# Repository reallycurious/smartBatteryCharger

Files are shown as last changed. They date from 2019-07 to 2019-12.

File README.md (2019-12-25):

# smartBatteryCharger (incomplete)
PIC12F1572 based Charger for 14.4V cordless drill

<b>Warning:</b> This charger design and accompanying code is based on a lot of assumptions. Some of which may or might not hold true. So if you want to adopt this design and/or code do so at your own risk.

After building a 2 meter by 2 meter cupboard and fastening all screws by hand I decided that a cordless drill is needed. So I bought the most inexpensive one I found. This cordless drill came with a 18v 400ma rated power adapter and charger stand that consists of few simple passive components: A 2W 10 Ohm resistor, an 4007 diode, two 3mm leds and two smd 0805 resistors one 2 KOhm the other 100 Ohm. Oh and instructions to charge 3-5 hours: which resulted in a very hot battery. I feared that it might vent electrolyte so I decided to replace electronics in charger stand, making it smarter.
  
So where to start designing a smart charger circuit that fits in housing of the old dumb one: a net search gave some ideas. Article <a href="https://batteryuniversity.com/learn/article/charging_nickel_based_batteries">Charging Nickel-cadmium @ batteryuniversity.com</a> is helpful but insufficient for designing a charger. <a href="http://electronics-diy.com/electronic_schematic.php?id=813">Intelligent NiCd/NiMH Battery Charger @ electronics-diy.com</a> was better: Although there is no source code as the author states "The source code is not freeware or shareware so please don't ask me to mail you the source code as it has commercial applications" reading the article gives a clear idea on how a smart chager should work and helped me designing the algorithm. <a href="https://electrosome.com/uart-pic-microcontroller-mplab-xc8/">Using UART of PIC Microcontroller – MPLAB XC8 @ electrosome.com</a> was helpful designing uart code. I had no such luck in pwm code, no practical examples for pic12f1572, so I cooked something from datasheet. Thankfully datasheet had sample assembly code for ADC.
  
You might ask, why pic12f1572 ? because with a 3,5 TL price tag for <a href="https://www.direnc.net/pic12f1572t-i-mf-dfn8-8bit-32mhz-mikrodenetleyici">dfn footprint version</a>, it was the cheapest but capable microcontroller that I could find at the time. And except its 10 bit ADC (not 12 bit) I think it is very suitable for the task. I should add that I had not programmed a PIC micro before. I had to learn pic programming (mostly reading the datasheet) for programming the pic12f1572.

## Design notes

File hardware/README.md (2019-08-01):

<b>WARNING: EXPERIMENTAL DESIGN</b><p>
<b>WARNING: DONT USE LINEAR VOLTAGE REGULATOR</b><p>

Linear Voltage Regulator Heat Up, may fry microcontroller (already had fried one microcontroller with LM7805) 
Currently using <a href="http://www.romanblack.com/smps/smps.htm">http://www.romanblack.com/smps/smps.htm</a> as smps. 
I might also use a buck converter ic.

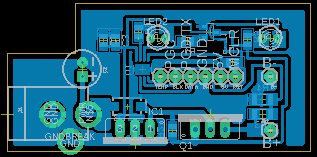
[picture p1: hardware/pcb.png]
pcb</img>
<p>
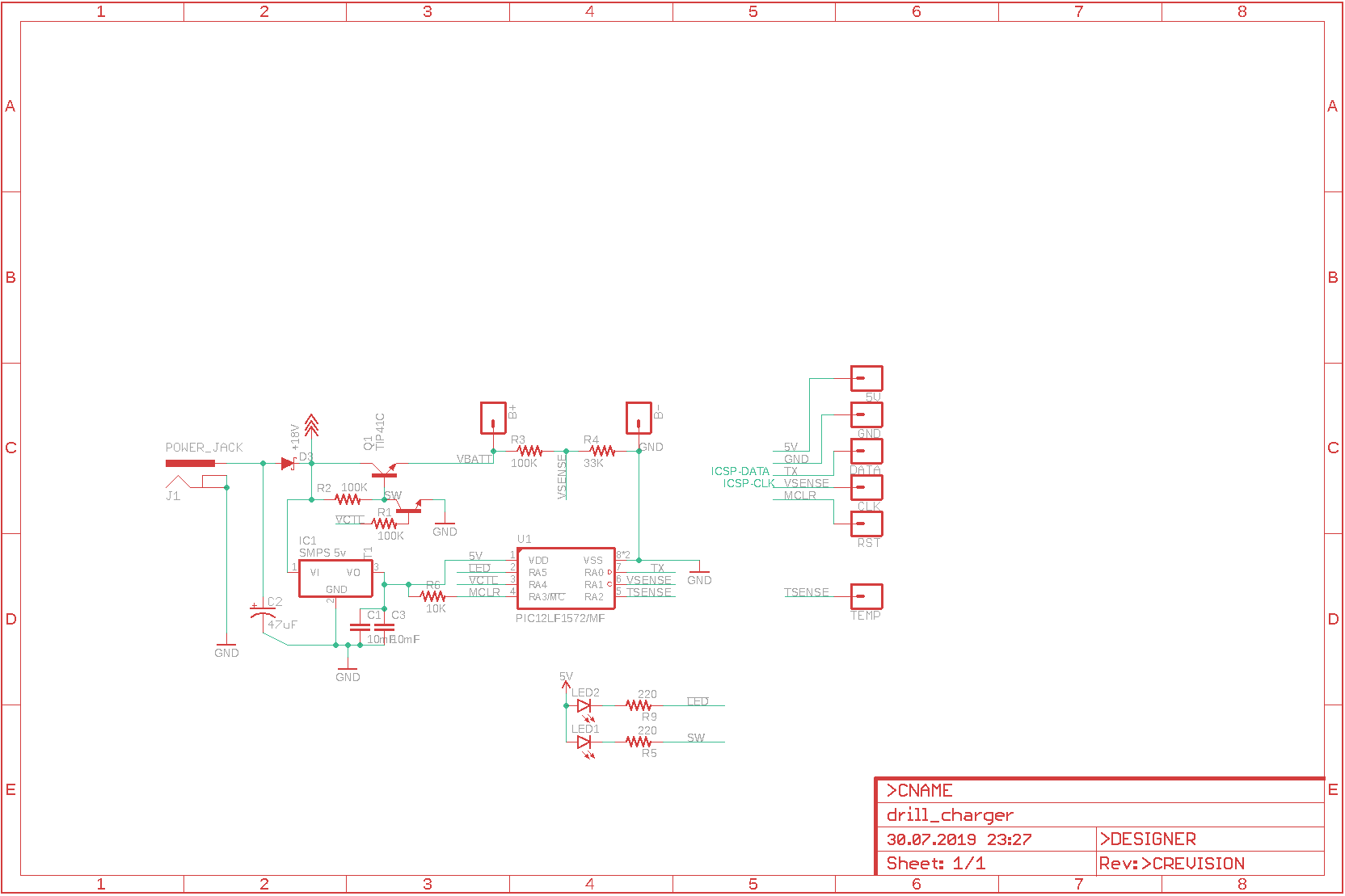
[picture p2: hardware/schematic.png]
schematic</img>

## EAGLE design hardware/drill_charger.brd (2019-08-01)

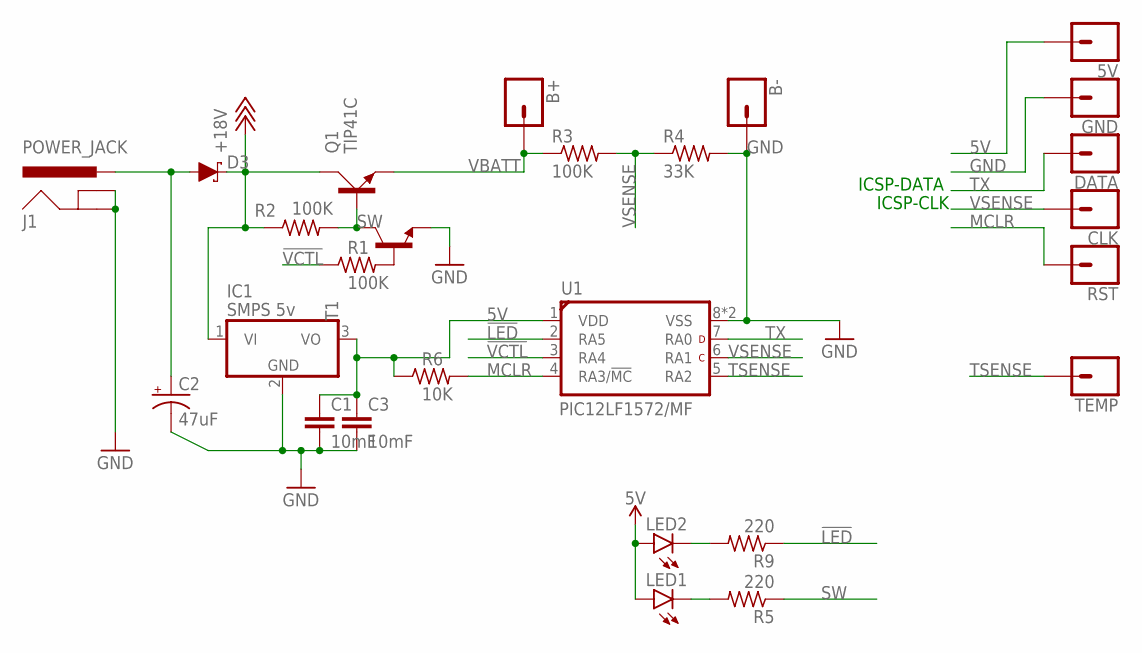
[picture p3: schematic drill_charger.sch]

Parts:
5V: CONN_01; 1X01
B+: CONN_01; 1X01
B-: CONN_01; 1X01
C1, C3: 10mF; C0805
C2: 47uF; CPOL-RADIAL-2.5MM-6.5MM
CLK: CONN_01; 1X01
D3: 1A/40V/500mV; SMA-DIODE
DATA: CONN_01; 1X01
GND: CONN_01; 1X01
IC1: SMPS 5v; TO220V
J1: POWER_JACK; POWER_JACK_PTH
LED1, LED2: LED3MM
Q1: TIP41C; TO220AV
R1, R2: 100K; R0805
R3: 100K; R1206
R4: 33K; R1206
R5, R9: 220; R0805
R6: 10K; R0805
RST: CONN_01; 1X01
T1: MMBT3904LT1-NPN-SOT23-BEC; SOT23-BEC
TEMP: CONN_01; 1X01
U1: PIC12LF1572/MF; DFN8-MF

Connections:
5V: 5V.1, C1.1, C3.1, IC1.3 (VO), LED1.A, LED2.A, R6.1, U1.1 (VDD)
!LED: R9.1, U1.2 (RA5)
!VCTL: R1.1, U1.3 (RA4)
+18V: D3.C, IC1.1 (VI), Q1.C, R2.1
GND: B-.1, C1.2, C2.2 (-), C3.2, GND.1, IC1.2 (GND), J1.GND, J1.GNDBREAK, R4.2, T1.E, U1.8 (VSS), U1.EP (VSS)
MCLR: R6.2, RST.1, U1.4 (RA3/!MC!)
unnamed: LED2.K (C), R9.2
unnamed: LED1.K (C), R5.2
unnamed: C2.1 (+), D3.A, J1.PWR
unnamed: R1.2, T1.B
SW: Q1.B, R2.2, R5.1, T1.C
TSENSE: TEMP.1, U1.5 (RA2)
TX: DATA.1, U1.7 (RA0)
VBATT: B+.1, Q1.E, R3.1
VSENSE: CLK.1, R3.2, R4.1, U1.6 (RA1)

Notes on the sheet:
ICSP-DATA
ICSP-CLK

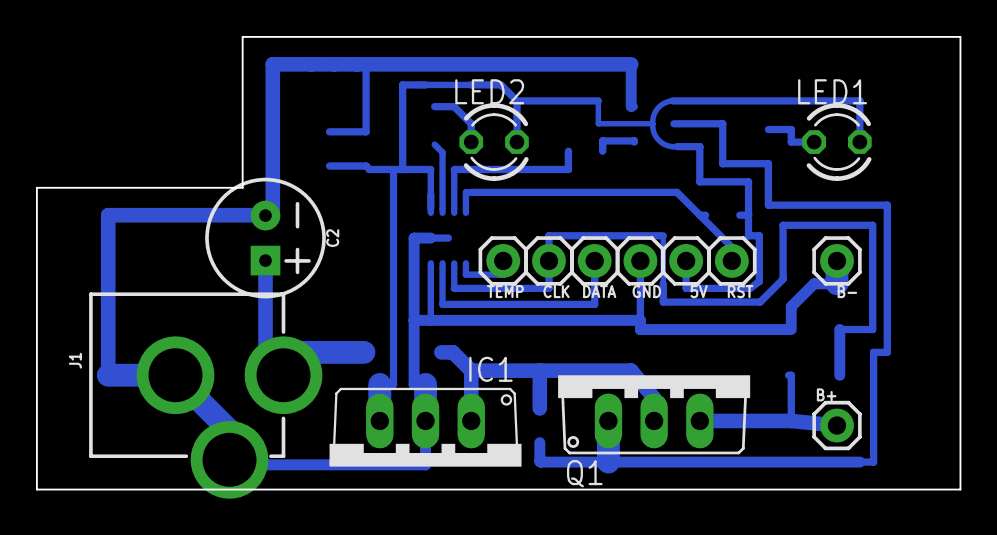
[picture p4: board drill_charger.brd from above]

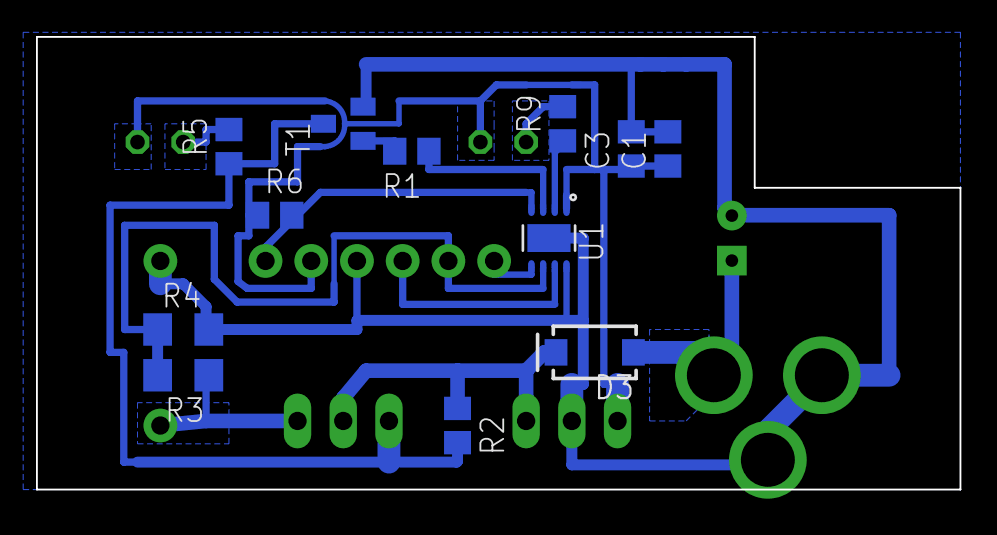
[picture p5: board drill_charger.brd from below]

Board: 2 copper layers, 51.3 x 25.1 mm, 26 parts (12 on the bottom side), 15 nets.

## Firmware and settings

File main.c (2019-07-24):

/*
 * File:   main.c
 * Author: storm
 *
 * Created on March 9, 2019, 5:36 PM
 */

// PIC12F1572 Configuration Bit Settings

// 'C' source line config statements

// CONFIG1
#pragma config FOSC = INTOSC    //  (INTOSC oscillator; I/O function on CLKIN pin)
#pragma config WDTE = ON        // Watchdog Timer Enable (WDT enabled)
#pragma config PWRTE = OFF      // Power-up Timer Enable (PWRT disabled)
#pragma config MCLRE = ON       // MCLR Pin Function Select (MCLR/VPP pin function is MCLR)
#pragma config CP = OFF         // Flash Program Memory Code Protection (Program memory code protection is disabled)
#pragma config BOREN = ON       // Brown-out Reset Enable (Brown-out Reset enabled)
#pragma config CLKOUTEN = OFF   // Clock Out Enable (CLKOUT function is disabled. I/O or oscillator function on the CLKOUT pin)

// CONFIG2
#pragma config WRT = OFF        // Flash Memory Self-Write Protection (Write protection off)
#pragma config PLLEN = OFF      // PLL Enable (4x PLL disabled)
#pragma config STVREN = ON      // Stack Overflow/Underflow Reset Enable (Stack Overflow or Underflow will cause a Reset)
#pragma config BORV = LO        // Brown-out Reset Voltage Selection (Brown-out Reset Voltage (Vbor), low trip point selected.)
#pragma config LPBOREN = OFF    // Low Power Brown-out Reset enable bit (LPBOR is disabled)
#pragma config LVP = ON         // Low-Voltage Programming Enable (Low-voltage programming enabled)

// #pragma config statements should precede project file includes.
// Use project enums instead of #define for ON and OFF.

//_XTAL_FREQ defined in main.h

#include "main.h"
#include <xc.h>
#include <pic12f1572.h>
#include <stdint.h>
#include <stdio.h>

//Charger states
#define STAND_BY    0
#define COOL_DOWN   1
#define SOFT_CHARGE 2
#define FAST_CHARGE 3
#define TRICKLE     4
#define CHRG_ERROR  255

//Other
#define vChannel    1   //channel for voltage read
#define chargePin   4   //PORTA 4 and PWM2 is reassigned to A4 in code
#define pwmChannel  2
#define ledPin      5   //PORTA 5

//pic12F1572 adc 10 bit (ref voltage 5V = 1024 => 1 unit 4,8828125 mV) 
//voltage divider R1=100K R2=33K (V0=(R1+R2/R2)*V1) v0=4,0303030303*v1
//1 unit is 4,0303030303 * 4,8828125 mV = 19,6792140151 mV ~ 20mV 
#define vUNIT 20 //20mV = 0.02v
#define vDISCONNECT 2*1000/vUNIT //2000mv (2 volt)
#define vERROR  10*1000/vUNIT //10000mv (10 volt)
#define vDELTA 60/vUNIT //12*5mV = 60mV (Charge cut off negative delta voltage / 5mV per cell)
#define MAX_VOLTAGE 19*1000/vUNIT //19v
#define MAX_PLATEAU 15*60   //15 minutes
#define MAX_CTIME  3*60*60 //3 hours

//function defines
#define readVoltage() aRead(vChannel)
#define chargeOn() chargePWM(255)
#define chargeOff() chargePWM(0)
#define ledOn() PORTA &= ~(1 << ledPin)
#define ledOff() PORTA |= (1 << ledPin)
#define ledToggle() PORTA ^= (1 << ledPin) //^ XOR

//TEXT
const char hello[]= "Smart Charger v1.0\r\n";

//VARS
char cState = STAND_BY; //Charger state 0 (stand by)
unsigned short vPeak = 0;
unsigned short plateauCounter = 0;
unsigned long chargeCounter = 0;


void chargePWM(unsigned char duty)
{           
    duty = ~duty; //reverse duty    
    if (duty == 0)
        PORTA &= ~(1 << chargePin);  
    else if (duty == 255)
        PORTA |= (1 << chargePin); 
    else
        initPWM(pwmChannel, duty); 
}

char batteryConnected()
{
    chargeOff();    
    if (readVoltage() < vDISCONNECT) return 0;
    return 1;
}

void Serial_Write_Text(char *text)
{
  short i = 0;
  while (text[i] != '\0')
  {
      UART_Write(text[i]);
      i ++;
  }   
}

void Serial_Write_Int(int i)
{
    char text_buffer[10];
    
    sprintf(text_buffer, "%d", i);        
    Serial_Write_Text((char *)text_buffer);
}

void Serial_Write_Volt(int v)
{
    int dec = v/51;
    int frac =(v%51)*2*100;
    frac = frac /51;
             
    Serial_Write_Int(dec);
    Serial_Write_Text((char *)".");
    Serial_Write_Int(frac);
}

void Serial_Write_Time(int time)
{
    char hour = time/3600;    
    char minute = (time%3600)/60;
    char second = time%60;  
             
    Serial_Write_Int(hour);
    Serial_Write_Text((char *)":");
    Serial_Write_Int(minute);
    Serial_Write_Text((char *)":");
    Serial_Write_Int(second);    
}

void checkDelta(int voltage)
{   
    //limit control
    if ( (plateauCounter > MAX_PLATEAU) || (voltage > MAX_VOLTAGE) )
        cState = TRICKLE;               
    //routine
    if (voltage > vPeak) 
            {
                plateauCounter = 0; //zero plateau counter
                vPeak = voltage;
            }                
    else if ( (vPeak - voltage) > vDELTA) 
        cState = TRICKLE;
    else //vCycle <= vPeak -> start timer                 
        plateauCounter++;    
}

void delay_1ms()
{
    __delay_ms(1); // Wait 1 ms
}

void delay_125ms()
{
    __delay_ms(125); // Wait 125 ms
}

void delay_1s()
{
    __delay_ms(1000); // Wait 1 s
}

void setup()
{
//BOOT UP HERE
    CLRWDT();   //clear watchdog timer
    delay_1ms(); // 1 ms Delay
    initADC(vChannel);
    //Start serial
    UART_Init_tx_only(9600);
    Serial_Write_Text((char *)hello);
    //Check if a battery is connected
    chargeOff();
    if (! batteryConnected())    
    {
        //Self Test
        chargeOn();
        delay_1s(); // 1 Second Delay
        if (readVoltage() < vERROR) cState = CHRG_ERROR;
        chargeOff();
    }
//END BOOT    
}

void loop()
{
    short vCycle = 0; //zero vCycle for averaging
    CLRWDT();   //clear watchdog timer
    switch(cState)
    {
        case STAND_BY:
            chargeOff();  
            ledOn();
            delay_1s();
            if (batteryConnected() ) 
                cState = COOL_DOWN;
            break;
        case COOL_DOWN: 
            ledOff();            
            for (char iCycle = 0; iCycle < 8; iCycle++) 
            {
                delay_125ms(); // Wait 125 ms
                vCycle += readVoltage();                           
            }                            
            vCycle = vCycle >> 3; //divide by 8                
            chargeCounter++;
            if (chargeCounter > 2) //3 seconds
                cState = SOFT_CHARGE;
            break;
        case SOFT_CHARGE:   //C/10 charge 
            ledToggle(); //toggle at 1 second
            chargePWM(76); // 76/256*400 ma 118.75 ma (C=1200 ma C/10=120 ma)            
            for (char iCycle = 0; iCycle < 8; iCycle++) 
            {                
                delay_125ms(); //wait 125 ms
                vCycle += readVoltage();
            }
            vCycle = vCycle >> 3; //divide by 8
            chargeCounter ++; //add 1 sec             
            checkDelta(vCycle);            
            if (chargeCounter > 4*60) //4 minutes
                cState = FAST_CHARGE;
            break;
        case FAST_CHARGE:                        
            chargeOn();            
            for (char iCycle=0; iCycle < 8; iCycle++)
            {                
                delay_125ms(); //wait 125 ms
                vCycle += readVoltage();
                ledToggle(); //toggle at 1/8 second
            }
            vCycle = vCycle >> 3; //Calculate average of 8 values (divide by 8)
            chargeCounter ++; //add 1 sec                        
            checkDelta(vCycle); 
            if (chargeCounter > MAX_CTIME)
                cState = TRICKLE;
            break;
        case TRICKLE:   //C/50 - C/20 charge
            ledOn(); //Led ON
            chargePWM(16); // 16/256*400ma = 25ma (C=1200ma C/50=24 ma)
            for (char iCycle = 0; iCycle < 8; iCycle++) //chargePWM is 100ms
            {                
                delay_125ms(); //wait 125 ms
                vCycle += readVoltage();
            }
            vCycle = vCycle >> 3; //divide by 8
            checkDelta(vCycle);
            chargeCounter ++; //add 1 sec
            //Check battery
            if (! batteryConnected() ) 
                cState = STAND_BY;            
            break;
        case CHRG_ERROR:
            chargeOff();            
            ledToggle(); // LED toggle
            for (char iCycle=0; iCycle < 20; iCycle++)
                delay_1ms(); // Fast blink led (0.02 Second Delay)
        break;
        default:
            cState = CHRG_ERROR; //unexpected state is error
    }
    //DEBUG
    Serial_Write_Text("State: ");
    Serial_Write_Int(cState);    
    Serial_Write_Text(" Charge: ");
    Serial_Write_Time(chargeCounter);
    Serial_Write_Text(" Plateau: ");
    Serial_Write_Time(plateauCounter);
    Serial_Write_Text(" vPeak: ");
    Serial_Write_Volt(vPeak);
    Serial_Write_Text(" vAvg: ");
    Serial_Write_Volt(vCycle);
    Serial_Write_Text("\r\n");
}

void main(void) {
    //OSCCON bit7 soft PLLx4 enable (1) bit6:3 freq (1110 = 8Mhz) 
    //bit2 unimplemented (0) bit1:0 (00 = clock src determined by config word)    
    OSCCON = 0b11110000; //internal oscillator @32Mhz
    delay_1ms(); //let clock sck settle
    
    //WDTCON bit7:6 unimplemented bit5:1 01101 (8s) bit0: 1 (wdt enable)    
    WDTCON = 0b00011011; //set watchdog timer 8sec
    
    //ANSELA bits are default to analog after reset
    PORTA = 0; //init PORTA
    LATA = 0; //clear data latch
    ANSELA = 0; //clear ANSELA bits
    //A5 output (led), A4 output (VCTL), A3 input (MCLR), A2 input (TSENSE)
    //A1 input (VSENSE), A0 output (TX)
    TRISA = 0b00001110; 
        
    //APFCON: ALTERNATE PIN FUNCTION CONTROL REGISTER
    //7         6       5       4   3       2       1       0
    //RXDTSEL   CWGASEL CWGBSEL ?   T1GSEL  TXCKSEL P2SEL   P1SEL
    APFCON |= 0b00000010; //Select A4 Alternate function PWM2
    SLRCONA &= 0b00100111; //disable slew rate limiting for A4
            
//Start
    setup();    //Setup
        while(1) 
    {        
        loop(); //main loop
    }
//END PROGRAM          
}

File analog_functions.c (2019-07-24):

#include "main.h"

char initADC(char channel)
{
    if (channel > 3)
        return 0; //only channels 0-3 available
    //Analog input preperation    
    TRISA |= (1 << channel); //set channel to input
    ANSELA |= (1 << channel); //set channel to analog input
    //FVRCON bit7 enable, bit6 ready(always 1), bit 5 temparature indicator enable, 
    //bit 4 temp indicator range selection, bit 3:2 comparator gain, bit 1:0 fvr buffer gain    
    //FVRCON = FVRCON | 0b00001111; //comparator gain 4x, fvr gain 4x
    //if ( !(FVRCON | 0b10000000)) FVRCON = FVRCON | 0b10000000; //if not enabled enable Fixed Voltage Reference
    //__delay_ms(1); //let fvr settle

    //ADCON1 bi7: justification (1 right, 0 left), bit6-5 clock select (111 FRC), 
    //bit3:2 unimplemented, bit 1:0 reference select (00 vdd-vss, 11 fvr, 10 external vref)
    ADCON1 = 0b11110000; //Right justify, FRC oscillator, Vdd and Vss Vref+ use FVR
    WPUA &= ~(1 << channel); //disable weak pullup on channel
    return 1;
}

short aRead(unsigned char channel)
{
    short result; 
    
    //ADCON bits 6:2 are channel select AN0=0b00000000, AN1=0b00000100 
    //AN2=0b00001000, AN3=0b00001100, Temp=0b01110100
    //ADCON bit 1 is GO/DONE and bit 0 is ADON (enable ADC)
    ADCON0 = channel << 2; //set channel select bits
    ADCON0 = ADCON0 | 0b00000001; //(ADON); //turn ADC on    
     __delay_ms(1); //acquisition delay (actually microseconds)
    ADCON0 = ADCON0 | 0b00000010; //(ADGO); //start conversion
    while (ADCON0 & 0b00000010) //(ADGO) )  
        {
        //wait for conversion 
        }
    ADCON0 = ADCON0 & 0b11111110; //turn ADC off
    result = (ADRESH << 8) | ADRESL; //combine two 8bit values into a 16bit val 
    return (result);
}

//Standard mode (MODE<1:0> = 00)
//PWM PERIOD IN STANDARD MODE
//Period = (PWMxPR + 1)*Prescale / PWMxCLK
//Duty Cycle = (PWMxDC ? PWMxPH) / (PWMxPR + 1)
//Independent Run mode (OFM<1:0> = 00)

//PWMxCON: PWMx CONTROL REGISTER
//7   6   5   4   3   2       1   0
//EN  OE  OUT POL MODE<1:0>   unimplemented
//PWMxCLKCON: PWMx CLOCK CONTROL REGISTER
//7             6   5   4       3       2       1       0
//unimplemented prescaler[2:0]  unimplemented   clock_source[1:0]
//111 = Divides clock source by 128             00 = FOSC

#define PWM_CONFIG      0b11100000  //EN=1, OE=1, OUT=1, POL=1, MODE=00, unimplemented=00
#define PWM_CLKCONFIG   0b00000000; //PRESCALER = /1(bits 6:5:4) CLK_SRC=F_OSC
#define PWM_PERIOD      ( (_XTAL_FREQ ) / freq) - 1 //((F_OSC/1)/freq)-1
#define PWM_PHASE       0
#define PWM_OFFSET_CFG  0b00000001;
#define PWM_DUTY        ((PWM_PERIOD +1)*duty >> 8) //duty 0-255


char initPWM(char channel, unsigned char duty)
{    
    unsigned long freq = ( (_XTAL_FREQ ) >> 8); //maximum frequency divisible by 256
    //Set pwm period    
    switch(channel)
    {
        case 1:
            PWM1CON = PWM_CONFIG;
            PWM1CLKCON = PWM_CLKCONFIG;
            PWM1PR = PWM_PERIOD;
            PWM1PH = PWM_PHASE;
            PWM1DC = PWM_DUTY;
            //PWM1OFCON = PWM_OFFSET_CFG;
            break;
        case 2:
            PWM2CON = PWM_CONFIG;
            PWM2CLKCON = PWM_CLKCONFIG;
            PWM2PR = PWM_PERIOD;
            PWM2PH = PWM_PHASE;
            PWM2DC = PWM_DUTY;
            //PWM2OFCON = PWM_OFFSET_CFG;
            break;
        case 3 :
            PWM3CON = PWM_CONFIG;
            PWM3CLKCON = PWM_CLKCONFIG;
            PWM3PR = PWM_PERIOD;
            PWM3PH = PWM_PHASE;
            PWM3DC = PWM_DUTY;
            //PWM3OFCON = PWM_OFFSET_CFG;
            break;
        default: return 0; //illegal channel
    }
    return 1;
}

void stopPWM(char channel)
{
    switch(channel)
    {
        case 1:
            PWM1CON &= ~(1 << 7); //disable
            break;
        case 2:
            PWM2CON &= ~(1 << 7); //disable
            break;            
        case 3:
            PWM3CON &= ~(1 << 7); //disable
            break;                    
    }
}

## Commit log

2019-07-23 somewhat working code and hardware
    [drill_charger.brd, drill_charger.sch]
2019-07-24 pwm code & cleanup

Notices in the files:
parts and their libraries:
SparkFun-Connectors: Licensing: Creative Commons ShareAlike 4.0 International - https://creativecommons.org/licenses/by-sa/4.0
